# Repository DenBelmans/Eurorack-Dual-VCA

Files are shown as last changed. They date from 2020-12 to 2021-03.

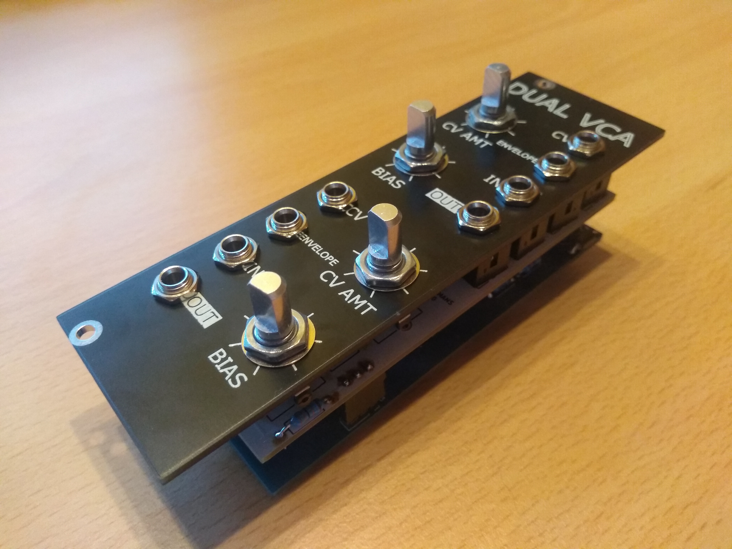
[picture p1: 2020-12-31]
VCA Picture.jpg

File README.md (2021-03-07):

# Eurorack-Dual-VCA
An 8hp dual VCA module for Eurorack. Based on Electricdruids 'Vintage VCA'. You can learn everything about the schematic on their blog: https://electricdruid.net/design-a-eurorack-vintage-vca-with-the-lm13700/

This is my first Eurorack module, I hope there are many more to come!
If you try this out, feel free to contact me with questions, critique, or send me some pictures of the finished product!

If there are any issues with any of the files, please contact me. I made this before I knew I would be sharing everything online.

***** BUILD INSTRUCTIONS *****

To make your lifes easier I have updated the silkscreen to include the component values.
While soldering the headers, I recommend you stack the pcb's with the unsoldered headers mated in between. Then fix the PCBs together with the standoffs and screws to keep things together. Then solder the connectors.
When installing the front panel, make sure the text on the panel is oriented in the same direction as the text on the PCBs. Otherwise things will not work as expected. In future designs I will try to make the panel non-symmetrical.

***** HISTORY *****

31/12/2020: First tests showed some issues with the design which were solved before uploading the files to GitHub, though the current files are not tested yet, this will likely happen later this month when I place a new order for PCBs.

20/01/2021: I have changed a few small things and will be ordering the current PCB design in the next week. I will update this description once I have tested it and confirmed that everything works as intended, no reversed pots or switched jacks :)

07/02/2021: As of today everything in this repository is finalized and tested. Feel free to place orders for PCBs with the provided gerbers or make changes using the KiCAD files!

07/03/2021: I updated the gerbers and kicad files again. Now the component values will be printed on the PCBs in silkscreen for easier assembly!

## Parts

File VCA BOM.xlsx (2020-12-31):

Dual VCA BOM
VCA top BOM
Part | Amount
Thonkiconn PJ398SM | 8 | Also 8 nuts for those
Alpha 9mm pots - vertical D-shaft 100K | 4 | Also 4 nuts for those
330k Resistor THT L6.3mm D2.5mm | 6 | 1% metal film
120K Resistor THT L6.3mm D2.5mm | 2 | 1% metal film
10uF electrolytic capacitor L6.0mm D5.0mm P2.5mm | 1
M3 bolts L6.0mm | 2
M3 11mm hex standoff | 2
1x03 Male header 2.54mm pitch | 2
1x02 Male header 2.54mm pitch | 1
VCA bottom BOM
Part | Amount
1x03 Female header 2.54mm pitch | 2
1x02 Female header 2.54mm pitch | 1
2x05 Male header 2.54mm pitch | 1 | Or proper Eurorack power connector
1nF ceramic capacitor THT | 2
10uF electrolytic capacitor L6.0mm D5.0mm P2.5mm | 2
100nF ceramic capacitor P5.00mm | 8 | Make sure to get small ones, I used something like this: https://www.mouser.be/ProductDetail/KEMET/C420C104K5R5TA7200/
1N4148 small signal diode THT | 4
Ferrite bead | 2
M3 bolts L6.0mm | 2
2N3906 PNP transistor | 2
33k Resistor THT L6.3mm D2.5mm | 2 | 1% metal film
1k Resistor THT L6.3mm D2.5mm | 4 | 1% metal film
100k Resistor THT L6.3mm D2.5mm | 4 | 1% metal film
470R Resistor THT L6.3mm D2.5mm | 2 | 1% metal film
6k8 Resistor THT L6.3mm D2.5mm | 2 | 1% metal film
680R Resistor THT L6.3mm D2.5mm | 4 | 1% metal film
27k Resistor THT L6.3mm D2.5mm | 2 | 1% metal film
TL072 DIP8 | 2
LM13700 DIP16 | 1
DIP8 socket | 2
DIP16 socket | 1

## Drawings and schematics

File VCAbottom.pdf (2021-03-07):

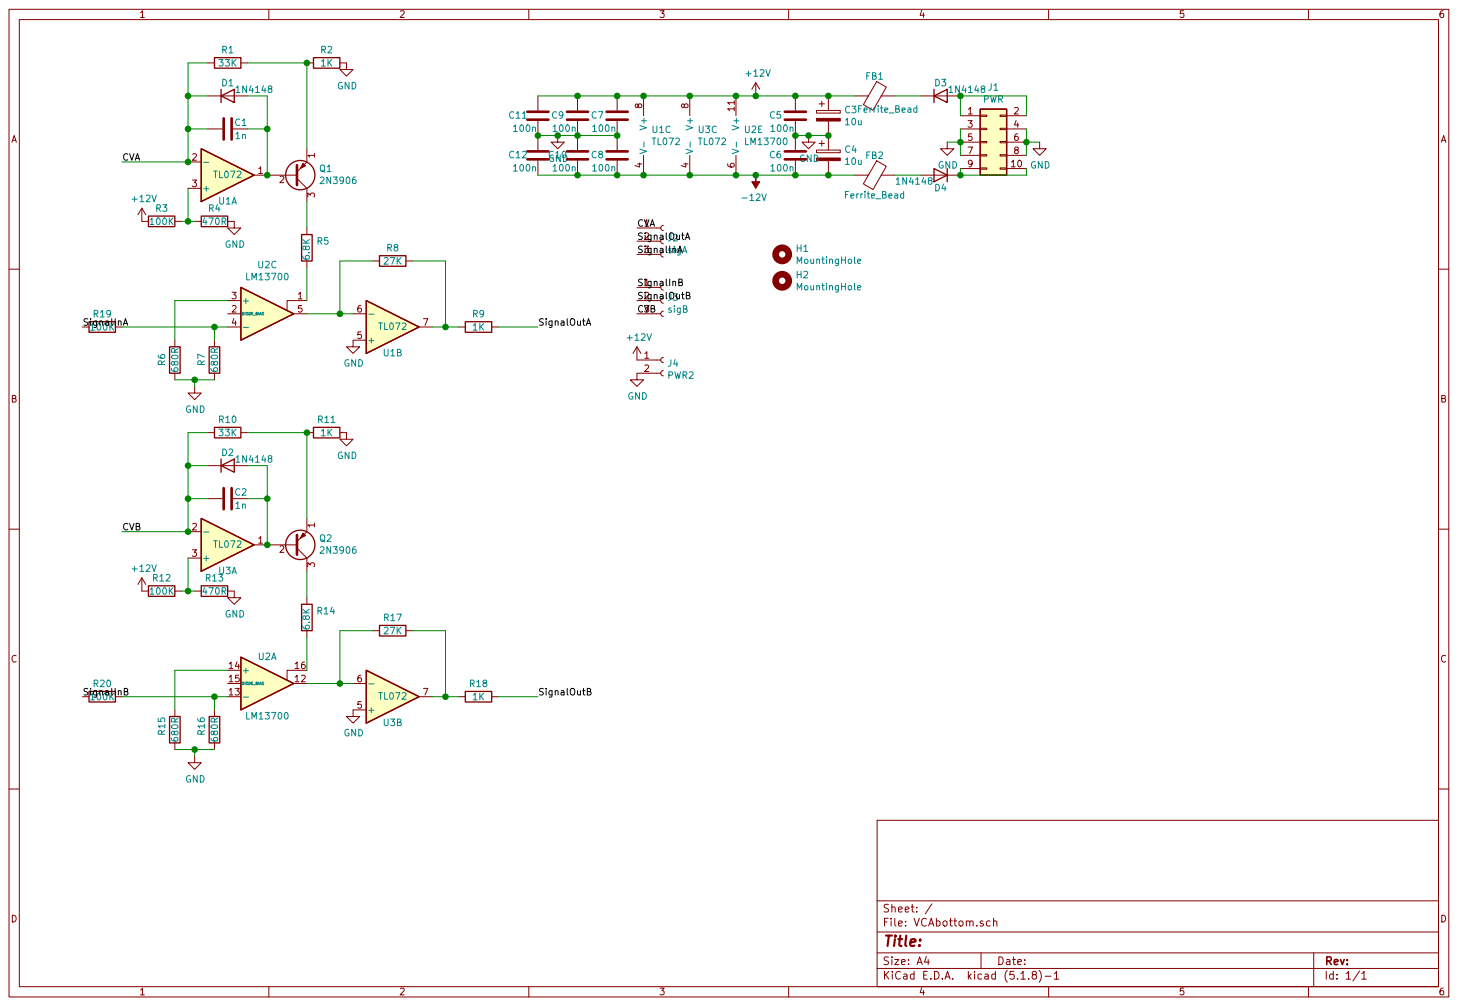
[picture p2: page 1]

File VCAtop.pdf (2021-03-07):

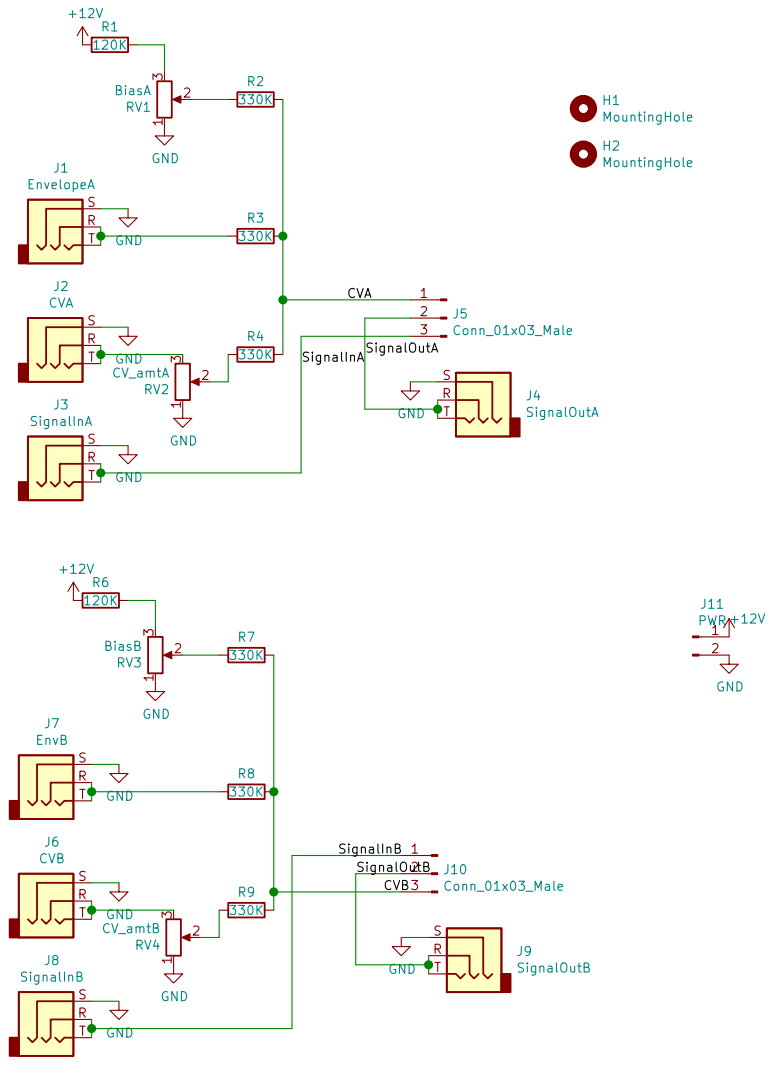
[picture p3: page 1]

File: VCAtop.sch Sheet: /

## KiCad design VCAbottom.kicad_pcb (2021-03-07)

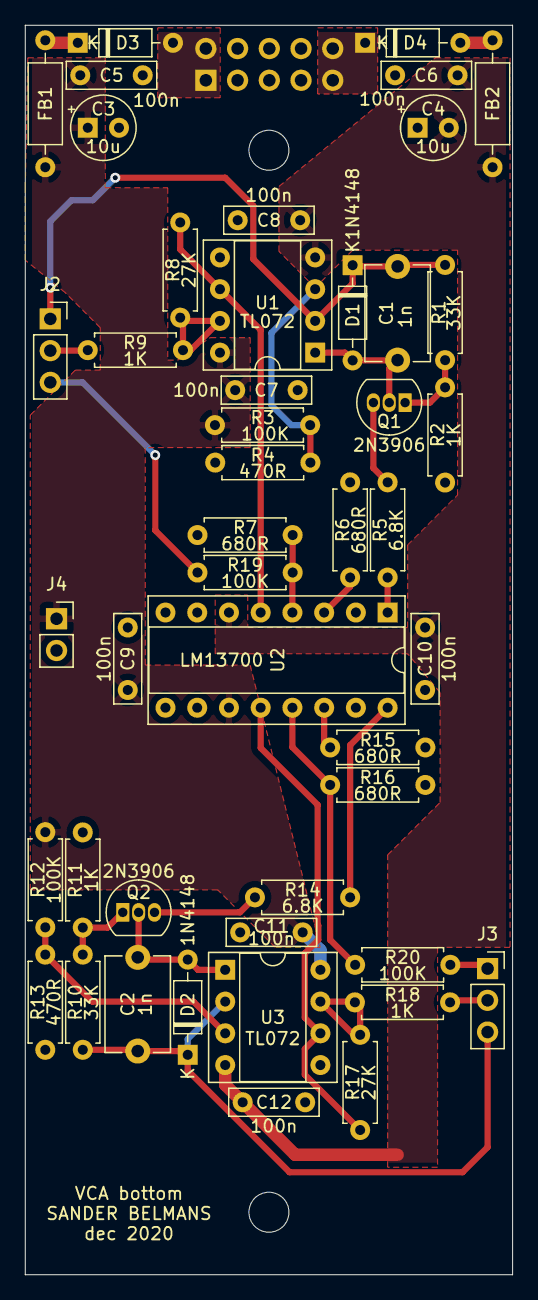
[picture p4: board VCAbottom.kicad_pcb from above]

Board: 2 copper layers, 39.0 x 100.0 mm, 49 parts (1 on the bottom side), 31 nets.

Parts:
C1, C2: 1n; C_Disc_D7.5mm_W5.0mm_P7.50mm
C3, C4: 10u; CP_Radial_Tantal_D5.0mm_P2.50mm
C5, C6, C7, C8, C9, C10, C11, C12: 100n; C_Rect_L7.0mm_W2.0mm_P5.00mm
D1, D2, D3, D4: 1N4148; D_DO-35_SOD27_P7.62mm_Horizontal
FB1, FB2: Ferrite_Bead; R_Axial_DIN0207_L6.3mm_D2.5mm_P10.16mm_Horizontal
H1, H2: MountingHole; MountingHole_3.2mm_M3
J1: PWR; PinSocket_2x05_P2.54mm_Vertical
J2: sigA; PinSocket_1x03_P2.54mm_Vertical
J3: sigB; PinSocket_1x03_P2.54mm_Vertical
J4: PWR2; PinSocket_1x02_P2.54mm_Vertical
Q1, Q2: 2N3906; TO-92_Inline
R1, R10: 33K; R_Axial_DIN0207_L6.3mm_D2.5mm_P7.62mm_Horizontal
R2, R9, R11, R18: 1K; R_Axial_DIN0207_L6.3mm_D2.5mm_P7.62mm_Horizontal
R3, R12, R19, R20: 100K; R_Axial_DIN0207_L6.3mm_D2.5mm_P7.62mm_Horizontal
R4, R13: 470R; R_Axial_DIN0207_L6.3mm_D2.5mm_P7.62mm_Horizontal
R5, R14: 6.8K; R_Axial_DIN0207_L6.3mm_D2.5mm_P7.62mm_Horizontal
R6, R7, R15, R16: 680R; R_Axial_DIN0207_L6.3mm_D2.5mm_P7.62mm_Horizontal
R8, R17: 27K; R_Axial_DIN0207_L6.3mm_D2.5mm_P7.62mm_Horizontal
U1, U3: TL072; DIP-8_W7.62mm_Socket
U2: LM13700; DIP-16_W7.62mm_Socket

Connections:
+12V: C3.1, C5.2, C7.2, C9.2, C11.2, FB1.2, J4.1, R3.2, R12.2, U1.8, U2.11, U3.8
-12V: C4.2, C6.1, C8.1, C10.1, C12.1, FB2.2, U1.4, U2.6, U3.4
/CVA: C1.2, D1.1, J2.1, R1.2, U1.2
/CVB: C2.2, D2.1, J3.3, R10.2, U3.2
/SignalInA: J2.3, R19.2
/SignalInB: J3.1, R20.2
/SignalOutA: J2.2, R9.1
/SignalOutB: J3.2, R18.1
GND: C3.2, C4.1, C5.1, C6.2, C7.1, C8.2, C9.1, C10.2, C11.1, C12.2, J1.3, J1.4, J1.5, J1.6, J1.7, J1.8, J4.2, R2.1, R4.1, R6.2, R7.2, R11.1, R13.1, R15.2, R16.2, U1.5, U3.5
unnamed: C1.1, D1.2, Q1.2, U1.1
unnamed: C2.1, D2.2, Q2.2, U3.1
unnamed: D3.1, FB1.1
unnamed: D3.2, J1.1, J1.2
unnamed: D4.1, J1.9, J1.10
unnamed: D4.2, FB2.1
unnamed: Q1.1, R1.1, R2.2
unnamed: Q1.3, R5.2
unnamed: Q2.1, R10.1, R11.2
unnamed: Q2.3, R14.2
unnamed: R3.1, R4.2, U1.3
unnamed: R5.1, U2.1
unnamed: R6.1, U2.3
unnamed: R8.1, R9.2, U1.7
unnamed: R8.2, U1.6, U2.5
unnamed: R12.1, R13.2, U3.3
unnamed: R14.1, U2.16
unnamed: R15.1, U2.14
unnamed: R16.1, R20.1, U2.13
unnamed: R17.1, R18.2, U3.7
unnamed: R17.2, U2.12, U3.6
unnamed: R7.1, R19.1, U2.4

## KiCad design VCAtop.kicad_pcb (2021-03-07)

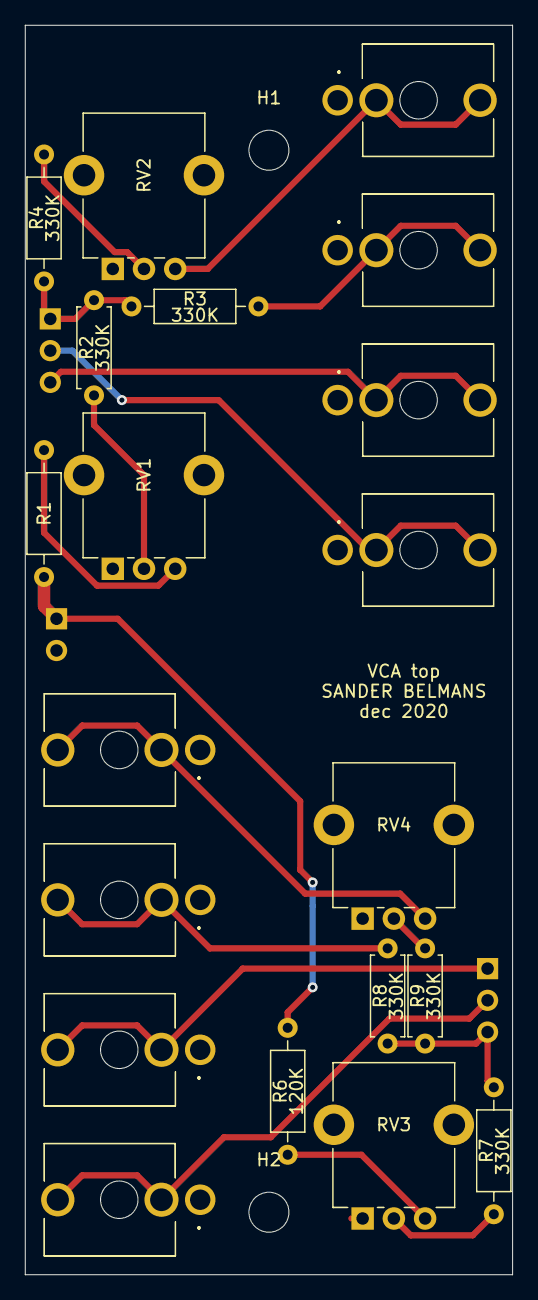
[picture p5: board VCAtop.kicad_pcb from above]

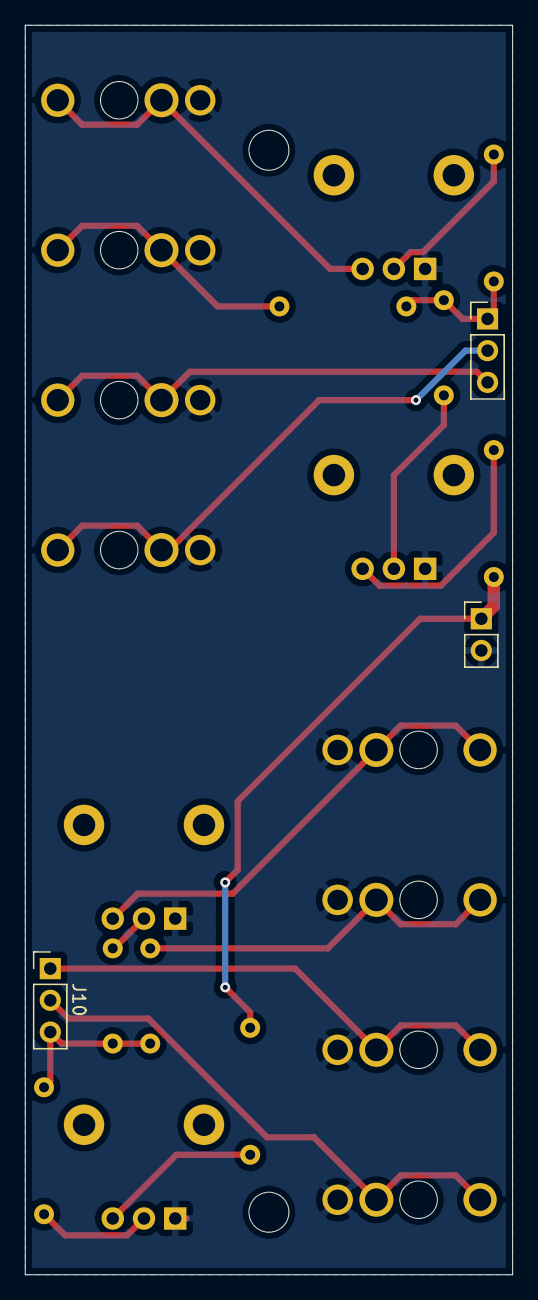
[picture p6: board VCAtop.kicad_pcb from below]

Board: 2 copper layers, 39.0 x 100.0 mm, 25 parts (3 on the bottom side), 18 nets.

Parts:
H1, H2: MountingHole; MountingHole_3.2mm_M3
J1: EnvelopeA; Thonkiconn
J2: CVA; Thonkiconn
J3: SignalInA; Thonkiconn
J4: SignalOutA; Thonkiconn
J5, J10: Conn_01x03_Male; PinHeader_1x03_P2.54mm_Vertical
J6: CVB; Thonkiconn
J7: EnvB; Thonkiconn
J8: SignalInB; Thonkiconn
J9: SignalOutB; Thonkiconn
J11: PWR; PinHeader_1x02_P2.54mm_Vertical
R1, R6: 120K; R_Axial_DIN0207_L6.3mm_D2.5mm_P10.16mm_Horizontal
R2, R8, R9: 330K; R_Axial_DIN0207_L6.3mm_D2.5mm_P7.62mm_Horizontal
R3, R4, R7: 330K; R_Axial_DIN0207_L6.3mm_D2.5mm_P10.16mm_Horizontal
RV1: BiasA; Potentiometer_Alpha_RD901F-40-00D_Single_Vertical_CircularH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
RV2: CV_amtA; Potentiometer_Alpha_RD901F-40-00D_Single_Vertical_CircularH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
RV3: BiasB; Potentiometer_Alpha_RD901F-40-00D_Single_Vertical_CircularH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
RV4: CV_amtB; Potentiometer_Alpha_RD901F-40-00D_Single_Vertical_CircularH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

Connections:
+12V: J11.1, R1.2, R6.2
/CVA: J5.1, R2.1, R3.1, R4.1
/CVB: J10.3, R7.1, R8.1, R9.1
/SignalInA: J3.R, J3.T, J5.3
/SignalInB: J8.R, J8.T, J10.1
/SignalOutA: J4.R, J4.T, J5.2
/SignalOutB: J9.R, J9.T, J10.2
GND: J1.S, J2.S, J3.S, J4.S, J6.S, J7.S, J8.S, J9.S, J11.2, RV1.1, RV2.1, RV3.1, RV4.1
unnamed: J1.R, J1.T, R3.2
unnamed: J2.R, J2.T, RV2.3
unnamed: J6.R, J6.T, RV4.3
unnamed: J7.R, J7.T, R8.2
unnamed: R1.1, RV1.3
unnamed: R2.2, RV1.2
unnamed: R4.2, RV2.2
unnamed: R6.1, RV3.3
unnamed: R7.2, RV3.2
unnamed: R9.2, RV4.2

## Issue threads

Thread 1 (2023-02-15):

Capacitor C1 & C2

hanebuechenes, 2023-02-15:
What capacitors you use here? The pitch seems 7,5mm. Is it some foil capacitor? But in BOM it is a ceramic. But my ceramic 1nF mostly have 2,5 oder 5mm pitch..

DenBelmans, 2023-02-15:
Any ceramic cap that fits should be fine. Just bend the leads a bit wider!

Op wo 15 feb. 2023 16:12 schreef Hanebuechenes ***@***.***>:

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

djfunkermix, 2025-01-25:
10p  difficult points of welding，I'm done。
